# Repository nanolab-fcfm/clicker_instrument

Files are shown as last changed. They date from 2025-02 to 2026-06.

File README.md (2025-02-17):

# ESP8266 Temperature Controller

This project allows controlling an ESP8266-based device through serial communication. The system simulates button presses to adjust temperature settings on an external device.

## 📦 Features
- **Set Current Temperature** (`SCTxxx`)
- **Set Target Temperature** (`STTxxx`)
- **Start Temperature Adjustment** (`GO`)
- **Query Current Temperature** (`RCT`)
- **Query Target Temperature** (`RTT`)
- **Manual Button Press Commands** (`A`, `AA`, `B`, `BB`, `AB`)

## 🔧 Requirements
- **ESP8266** microcontroller
- **USB-to-Serial Converter** (e.g., FTDI, CH340G)
- **Serial Terminal Software** (Minicom, Screen, Picocom, or Python `pyserial`)

## 🚀 Commands & Usage
### **Temperature Commands**
| Command | Description |
|---|---|
| `SCTxxx`  | Set **current** temperature to `xxx` °C. Example: `SCT30` (sets to 30°C) |
| `STTxxx`  | Set **target** temperature to `xxx` °C. Example: `STT100` (target = 100°C) |
| `RCT` | Request **current** temperature |
| `RTT` | Request **target** temperature |
| `GO` | Start adjusting temperature from `CT` to `TT` |

### **Manual Button Presses**
| Command | Action |
|---|---|
| `A` | Short press button A (100 ms) |
| `AA` | Long press button A (500 ms) |
| `B` | Short press button B (100 ms) |
| `BB` | Long press button B (500 ms) |
| `AB` | Short press both A and B simultaneously |

## 🔧 Troubleshooting
### **Permission Denied (Linux)**
If you get `permission denied` on `/dev/ttyUSB0`, run:
```bash
sudo usermod -aG dialout $USER
```
Then **restart the terminal**.

## 📌 Example Usage
```
SCT25   # Set current temperature to 25°C
STT80   # Set target temperature to 80°C
RCT     # Get current temperature
RTT     # Get target temperature
GO      # Start automatic temperature adjustment
```

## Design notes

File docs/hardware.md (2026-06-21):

# Hardware

## Interactive 3D model

Drag to rotate, scroll to zoom, right-drag to pan. This model is exported
directly from the KiCad board (`hw/clicker.kicad_pcb`) with `kicad-cli`.

<model-viewer
  src="../assets/3d/clicker.glb"
  alt="Interactive 3D model of the Clicker PCB with components"
  camera-controls
  auto-rotate
  touch-action="pan-y"
  environment-image="neutral"
  tone-mapping="neutral"
  exposure="0.95"
  shadow-intensity="1"
  shadow-softness="0.8"
  style="width: 100%; height: 520px; border-radius: 8px; background: radial-gradient(circle at 50% 35%, #2b313a 0%, #14161a 100%);">
</model-viewer>

!!! note "About the model"
    The board (green soldermask), copper/pads (gold) and the through-hole
    components — resistors `R101`–`R104`, transistors `Q101`/`Q102` and header
    `J101` — are shown. The ESP8266 module and the temperature module use custom
    footprints with no 3D model assigned, so they appear as their footprint pads
    without a body.

    KiCad's GLB export carries the **board** colours but drops the **component**
    materials (they would otherwise render solid white), so component meshes are
    recoloured in a small post-processing pass. To regenerate the model after a
    board change (no system install needed — just Docker):

    ```bash
    # 1) Export the board (with component geometry) to GLB
    docker run --rm -e KICAD9_3DMODEL_DIR=/usr/share/kicad/3dmodels \
      -v "$PWD":/work -w /work kicad/kicad:9.0 bash -lc \
      'apt-get update -qq && apt-get install -y --no-install-recommends kicad-packages3d >/dev/null && \
       kicad-cli pcb export glb -f --include-tracks --include-zones \
         -o docs/assets/3d/clicker.glb hw/clicker.kicad_pcb'
    # 2) Recolour the (material-less) component meshes — see tools/recolor_glb.py
    ```

## PCB Design

The Clicker is built on a custom KiCad PCB that interfaces an ESP8266 microcontroller with the actuators that press the MHP30's two buttons (A and B). The board uses a front/back copper stack (see the Gerbers below).

### PCB Files

All KiCad project files are located in the `hw/` directory:
- **clicker.kicad_sch**: Schematic diagram defining all electrical connections
- **clicker.kicad_pcb**: PCB layout with component placement and routing
- **clicker.kicad_pro**: KiCad project configuration

### Fabrication

Ready-to-manufacture Gerber files are in `hw/fab/`:
- **clicker-F_Cu.gbr**: Front copper layer
- **clicker-B_Cu.gbr**: Back copper layer
- **clicker-Edge_Cuts.gbr**: PCB outline
- **clicker-PTH.drl** / **clicker-NPTH.drl**: Plated and non-plated drill files
- **clicker-job.gbrjob**: Gerber job file with manufacturing notes

### Components

The custom symbol/footprint library (`hw/nanolab_hw_library.kicad_sym` and
`hw/nanolab_hw_library.pretty/`) defines the parts used on the board:

- **ESP** — the ESP8266 microcontroller module that runs the firmware and drives
  the two button outputs on **D1 (GPIO5)** and **D2 (GPIO4)**.
- **Temperature_module** — footprint for the temperature module.

!!! note
    For the authoritative component list and connections, open
    `hw/clicker.kicad_sch` in [KiCad](https://www.kicad.org/). The firmware pin
    assignment is documented on the [Firmware](firmware.md) page.

### Ordering the board

Upload the contents of `hw/fab/` to a PCB fab service (JLCPCB, OSH Park, …),
including the drill files (`*.drl`) for accurate hole drilling.

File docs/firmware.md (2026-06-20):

# Firmware

## Arduino Firmware

The firmware is a single Arduino sketch: **fw/clicker.ino** (C++ / Arduino IDE).

### Microcontroller & Board

- **Target Board**: ESP8266 (NodeMCU or equivalent)
- **Baud Rate**: 115200
- **Clock**: 80 MHz (default)

### Building & Flashing

1. **Install Arduino IDE** and the ESP8266 board package:
   - Board: ESP8266 Generic Module
   - Flash Size: 4MB / 1MB (SPIFFS)
   
2. **Open fw/clicker.ino** in Arduino IDE

3. **Flash to device**:
   - Select Tools → Board → ESP8266
   - Select Tools → Port → (your USB port, typically /dev/ttyUSB0 or /dev/cu.usbserial-*)
   - Sketch → Upload

### GPIO Pinout

```
D1 (GPIO5)  → Button A output (short/long press control)
D2 (GPIO4)  → Button B output (short/long press control)
```

Both pins start LOW and are pulled HIGH during a button press.

### Serial Protocol (115200 baud)

All commands are received as strings terminated by newline (`\n`) or carriage return (`\r`).

#### Temperature Commands

| Command | Example | Description |
|---|---|---|
| `SCTxxx` | `SCT30` | Set current temperature to xxx °C (stored in variable CT) |
| `STTxxx` | `STT100` | Set target temperature to xxx °C (stored in variable TT) |
| `RCT` | `RCT` | Query current temperature (responds with integer) |
| `RTT` | `RTT` | Query target temperature (responds with integer) |
| `GO` | `GO` | Automatically adjust from CT to TT using intelligent ramping algorithm |
| `*IDN?` | `*IDN?` | Query device identification (responds: `ROSATECH,CLK100,P0000003,1.0.0`) |

#### Manual Button Press Commands

| Command | Duration | Description |
|---|---|---|
| `A` | 100 ms | Short press button A |
| `AA` | 500 ms | Long press button A |
| `B` | 100 ms | Short press button B |
| `BB` | 500 ms | Long press button B |
| `AB` | 100 ms | Simultaneous short press of both A and B |

Unknown commands produce: `ERROR! Unknown command: <cmd>`

### Temperature Ramping Algorithm

The `GO` command executes `reachTargetTemperature()`, which:

1. Sends 2× AB (both buttons) to reset the MHP30 display
2. Sends 2× short press A to initialize the system
3. Uses large steps (long press A/B) to approach the target in 10 °C increments
4. Switches to single-step (short press A/B) for final 1 °C adjustments
5. Prevents overshoot with boundary checks

The algorithm minimizes time by:
- Long presses increase/decrease by 10 °C
- Short presses increase/decrease by 1 °C
- Detects direction (CT < TT vs CT > TT) and uses button A (up) or B (down)

### Key Variables

- **CT**: Current temperature (integer, °C)
- **TT**: Target temperature (integer, °C)
- **pressDelay**: Delay between successive presses (default 500 ms, tunable)

### Requirements

- Arduino IDE (or PlatformIO)
- ESP8266 board support package
- No external libraries required (uses only Serial and digitalWrite)

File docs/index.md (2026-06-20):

# Clicker

The Clicker Instrument is an automated button-pressing device designed to control the MHP30 hotplate's temperature settings. It uses an ESP8266 microcontroller to simulate precise button presses on the hotplate's physical interface, allowing remote temperature control via serial commands.

The device is integrated with laser_setup, which sends commands to set and reach target temperatures without manual button manipulation. It implements an intelligent algorithm that minimizes adjustment time by using long presses (500 ms) for large temperature increments and short presses (100 ms) for fine-tuning to the exact target.

## Key Features

- **Remote Temperature Control**: Set current and target temperatures via serial commands (SCT, STT)
- **Automatic Temperature Ramping**: Intelligent algorithm (`GO` command) that reaches the target temperature in minimal steps
- **Manual Button Control**: Direct button presses for manual operation (A, B, AA, BB, AB commands)
- **Query Capabilities**: Real-time temperature status queries (RCT, RTT)
- **Simple Serial Protocol**: Command-line interface at 115200 baud over USB-to-Serial

## Repository Structure

- **fw/clicker.ino**: Arduino firmware with all control logic
- **hw/**: KiCad PCB design (schematic, board layout, footprints)
- **hw/fab/**: Fabrication files (Gerber, drill files) for PCB manufacture
- **hw/nanolab_hw_library.kicad_sym**: Custom symbols for ESP8266 and temperature module
- **hw/nanolab_hw_library.pretty/**: Footprint library (ESP, Temperature_module)

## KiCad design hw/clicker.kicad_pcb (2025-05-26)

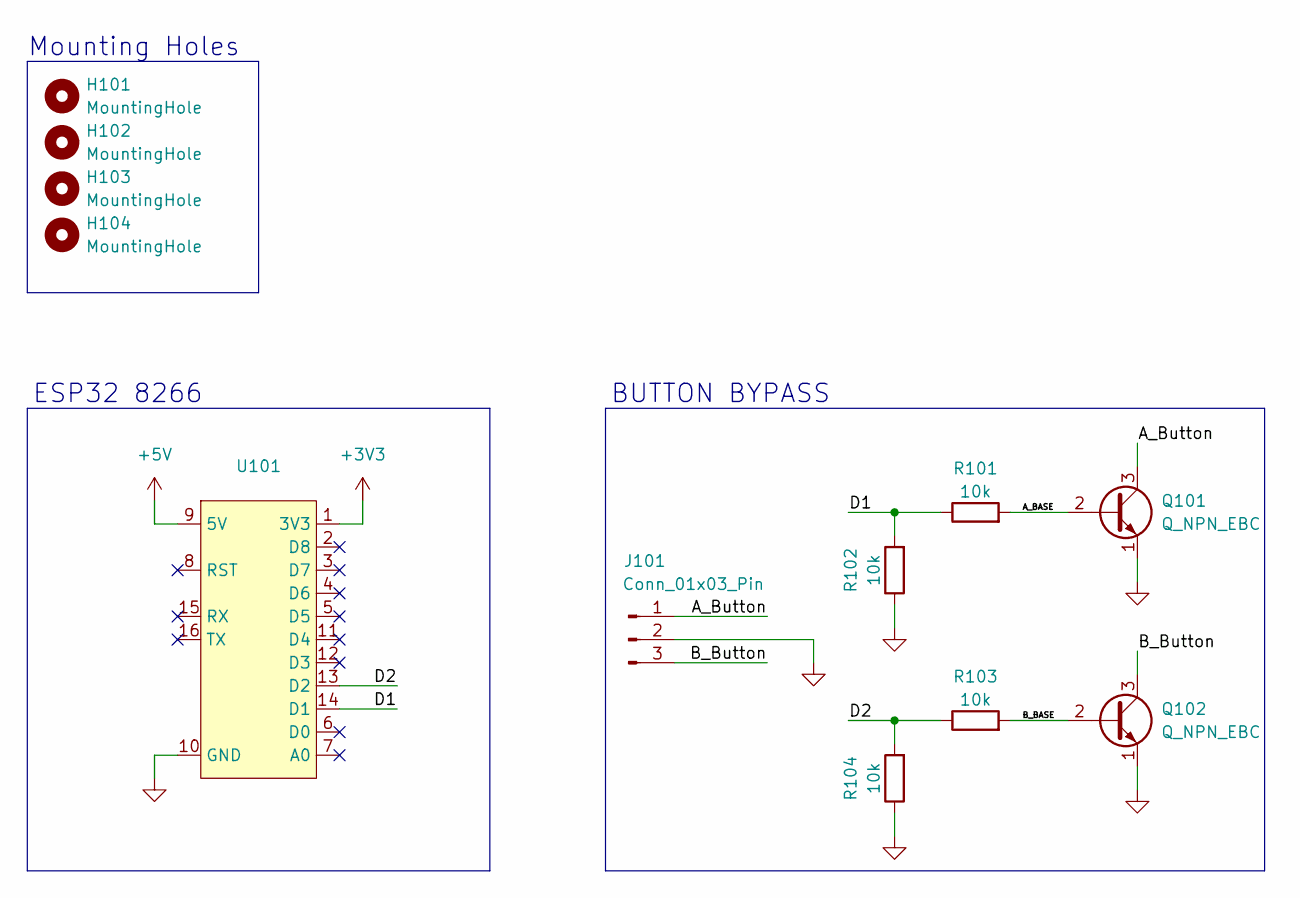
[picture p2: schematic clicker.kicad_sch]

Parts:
H101, H102, H103, H104: MountingHole; MountingHole_2.5mm
J101: Conn_01x03_Pin; PinHeader_1x03_P2.54mm_Vertical
Q101, Q102: Q_NPN_EBC; TO-92L_HandSolder
R101, R102, R103, R104: 10k; R_Axial_DIN0204_L3.6mm_D1.6mm_P7.62mm_Horizontal
U101: ESP

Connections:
+3V3: U101.1 (3V3)
+5V: U101.9 (5V)
/A_BASE: Q101.2 (B), R101.2
/A_Button: J101.1, Q101.3 (C)
/B_BASE: Q102.2 (B), R103.2
/B_Button: J101.3, Q102.3 (C)
/D1: R101.1, R102.2, U101.14 (D1)
/D2: R103.1, R104.2, U101.13 (D2)
GND: J101.2, Q101.1 (E), Q102.1 (E), R102.1, R104.1, U101.10 (GND)

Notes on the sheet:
Mounting Holes
BUTTON BYPASS
ESP32 8266

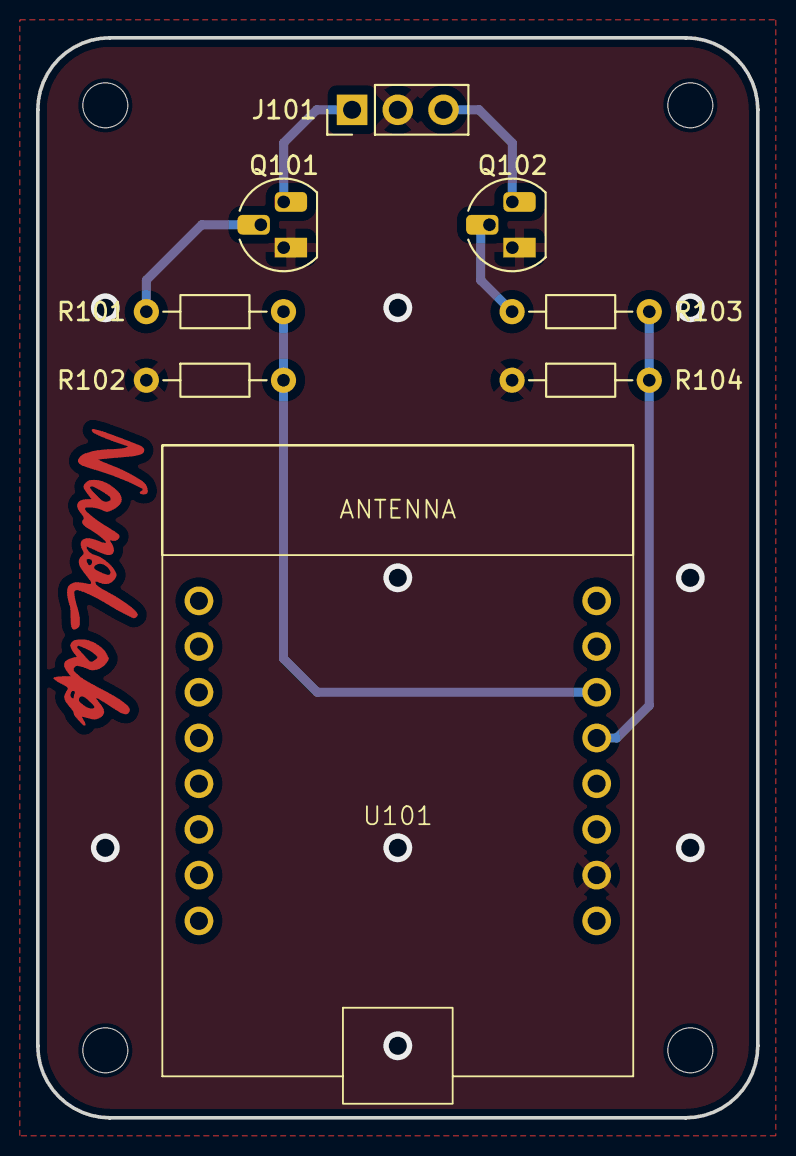
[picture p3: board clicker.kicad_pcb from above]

Board: 2 copper layers, 40.0 x 60.0 mm, 12 parts (0 on the bottom side), 7 nets.

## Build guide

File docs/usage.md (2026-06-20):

# Usage

## Operating the Clicker Instrument

Once the device is flashed with fw/clicker.ino and connected via USB serial, you can control it from any serial terminal or Python script.

### Serial Connection

**Linux/macOS**:
```bash
minicom -D /dev/ttyUSB0 -b 115200
# or
screen /dev/ttyUSB0 115200
# or
python3 -m serial.tools.miniterm /dev/ttyUSB0 115200
```

**Windows**:
- Use PuTTY or Arduino IDE Serial Monitor (set baud to 115200)

If you get permission denied on Linux, add your user to the dialout group:
```bash
sudo usermod -aG dialout $USER
# Restart terminal after this
```

### Basic Temperature Control

**Manual sequence** (e.g., set and reach 80 °C):

```
SCT25       # Current temperature is 25°C
STT80       # Target is 80°C
RCT         # Response: 25
RTT         # Response: 80
GO          # Device automatically presses buttons to reach 80°C
```

The firmware will adjust the MHP30's current temperature from 25°C to 80°C using the intelligent ramping algorithm.

### Manual Button Control

Press individual buttons without automated ramping:

```
A           # Quick press button A once (100 ms)
AA          # Long press button A (500 ms) — increases temp by ~10°C
B           # Quick press button B once (100 ms)
BB          # Long press button B (500 ms) — decreases temp by ~10°C
AB          # Press both simultaneously (reset/confirm on some devices)
```

### Integration with laser_setup

The `laser_setup` platform integrates the Clicker Instrument via its serial interface:

1. **Connect** the clicker to the computer's USB port (e.g., `/dev/ttyUSB0`)
2. **Configure** laser_setup to use the clicker's port and baud rate (115200)
3. **Call commands** like `SCT`, `STT`, `GO` to automate hotplate temperature ramps during laser experiments

Example flow:
- User specifies experiment temperature profile (e.g., 30°C → 100°C → 30°C)
- laser_setup sends `SCT30`, `STT100`, `GO` to the clicker
- Clicker automatically adjusts the MHP30 without user intervention
- laser_setup polls `RCT` to verify current temperature between steps

### Troubleshooting

**Device not responding**:
- Check USB connection and baud rate (must be 115200)
- Verify correct serial port is selected
- Press Ctrl+C in minicom/screen to reset the connection

**Button presses not working**:
- Confirm GPIO pins D1 (GPIO5) and D2 (GPIO4) are wired correctly
- Check relay/solenoid drivers are powered
- Test with `A` command; verify mechanical solenoid activates

**Temperature not reaching target**:
- Verify CT and TT are set correctly with `RCT`/`RTT`
- Check MHP30 is in a mode that responds to button presses
- Increase `pressDelay` variable in firmware if presses are being missed

**Device identification**:
Send `*IDN?` — should respond:
```
ROSATECH,CLK100,P0000003,1.0.0
```
If not present in response, re-flash the firmware.

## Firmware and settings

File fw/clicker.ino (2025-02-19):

#define A 5  // GPIO5 (D1 on NodeMCU)
#define B 4  // GPIO4 (D2 on NodeMCU)

String commandBuffer = "";  // Buffer to store incoming command
int CT = 0;  // Current Temperature
int TT = 0;  // Target Temperature
int pressDelay = 500; // Delay (ms) between button presses, adjustable manually

void setup() {
    pinMode(A, OUTPUT);
    digitalWrite(A, LOW);  // Ensure D1 (GPIO5) starts at 0V

    pinMode(B, OUTPUT);
    digitalWrite(B, LOW);  // Ensure D2 (GPIO4) starts at 0V

    Serial.begin(115200);  // Start serial communication
}

// Function to press a pin for 100ms (short press)
void shortPress(int pin) {
    digitalWrite(pin, HIGH);
    delay(100);
    digitalWrite(pin, LOW);
    delay(pressDelay); // Wait before next action
}

// Function to press a pin for 500ms (long press)
void longPress(int pin) {
    digitalWrite(pin, HIGH);
    delay(500);
    digitalWrite(pin, LOW);
    delay(pressDelay); // Wait before next action
}

// Function to press both A and B for 100ms simultaneously
void shortPressAB() {
    digitalWrite(A, HIGH);
    digitalWrite(B, HIGH);
    delay(100);
    digitalWrite(A, LOW);
    digitalWrite(B, LOW);
    delay(pressDelay); // Wait before next action
}

// Function to round up to the next multiple of 10 correctly
int roundUpToNext10(int num) {
    if (num % 10 == 0) {
        return num + 10;  // If already at a multiple of 10, go to the next one
    } else {
        return ((num / 10) * 10) + 10;  // Otherwise, round up normally
    }
}

// Function to round down correctly based on whether the number is a multiple of 10
int roundDownCorrectly(int num) {
    if (num % 10 == 0) {
        return num - 10;  // If at a multiple of 10, move to the closest lower one
    } else {
        return ((num / 10) * 10) - 10;  // If not a multiple of 10, move two steps down
    }
}

// Function to automatically adjust from CT to TT (minimizing time)
void reachTargetTemperature() {
    // Call AB command 2 times first
    for (int i = 0; i < 2; i++) {
        shortPressAB();
    }

    shortPress(A);  // Step 1: Start with a short press of A
    shortPress(A);  // Step 2: Start with a short press of A

    while (CT != TT) {
        if (CT < TT) {
            while (CT + 10 <= TT) {
                int nextTemp = roundUpToNext10(CT);
                if (nextTemp > TT) break;  // Ensure we don't overshoot
                
                longPress(A);
                CT = nextTemp;
            }

            while (CT < TT) {
                shortPress(A);
                CT += 1;
            }
        } 
        else if (CT > TT) {
            while (CT - 10 >= TT) {
                int nextTemp = roundDownCorrectly(CT);
                if (nextTemp < TT) break;  // Ensure we don't overshoot
                
                longPress(B);
                CT = nextTemp;
            }

            while (CT > TT) {
                shortPress(B);
                CT -= 1;
            }
        }
    }

   
    // **Set Current Temperature to Target Temperature**
    CT = TT;
}

void loop() {
    while (Serial.available() > 0) {
        char incomingChar = Serial.read();

        // Ignore newline and carriage return characters
        if (incomingChar == '\n' || incomingChar == '\r') {
            if (commandBuffer.length() > 0) {
                processCommand(commandBuffer);
                commandBuffer = "";  // Clear buffer after processing
            }
            return;
        }

        commandBuffer += incomingChar;  // Append character to buffer
    }
}

void processCommand(String command) {
    if (command == "A") {
        shortPress(A);
    } else if (command == "AA") {
        longPress(A);
    } else if (command == "B") {
        shortPress(B);
    } else if (command == "BB") {
        longPress(B);
    } else if (command == "AB") {
        shortPressAB();
    } else if (command.startsWith("SCT")) {
        CT = command.substring(3).toInt();
    } else if (command.startsWith("STT")) {
        TT = command.substring(3).toInt();
    } else if (command == "RCT") {
        Serial.println(CT);
    } else if (command == "RTT") {
        Serial.println(TT);
    } else if (command == "GO") {
        reachTargetTemperature();
    } else if (command == "*IDN?") {
        Serial.println("ROSATECH,CLK100,P0000003,1.0.0");
    } else {
        Serial.print("ERROR! Unknown command: ");
        Serial.println(command);
    }
}

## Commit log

2025-02-19 Fix extra "{" in main.ino
    [clicker.ino]
2025-05-26 clicker hw
    [clicker.kicad_pcb, clicker.kicad_sch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]
2025-05-26 gitignore for KiCAD files
2026-06-20 Add MkDocs documentation site
    Add a NanoLab-branded MkDocs Material documentation site (Overview, Hardware,
    Firmware, Usage) deployable to GitHub Pages at nanolab.cl/clicker_instrument/, consistent with
    the other NanoLab project docs. Includes the Pages deploy workflow and shared
    branding (logo, palette, footer, back-to-NanoLab link).
2026-06-21 Point back-link to the NanoLab documentation hub
    Change the '⬅ NanoLab' nav link to target nanolab.cl/documentation/ (the docs
    hub) instead of the site root, for consistent cross-navigation.
2026-06-21 Add interactive 3D PCB model to the hardware docs
    Export the KiCad board (with through-hole component 3D models) to GLB via
    kicad-cli and embed it with Google's <model-viewer> web component, so the
    Hardware page shows a rotate/zoom/pan 3D render of the PCB. Includes a documented
    Docker one-liner to regenerate the model after board changes.
2026-06-21 Fix 3D model: colour components and use a dark viewer background
    KiCad's GLB export omits component materials, so components rendered solid white
    on a light background. Add tools/recolor_glb.py to assign materials to the
    component meshes by reference designator (blue resistors, black transistors and
    header), regenerate the GLB, and give <model-viewer> a dark background with
    neutral tone-mapping so the board and parts read clearly.
